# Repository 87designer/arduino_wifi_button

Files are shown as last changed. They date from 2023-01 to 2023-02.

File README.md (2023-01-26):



<!-- PROJECT LOGO -->
<br />
<div align="center">
  <a href="https://github.com/87designer/arduino_infant_tracker">
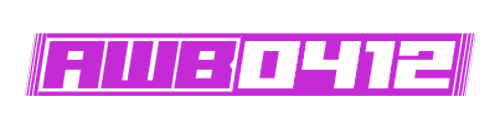
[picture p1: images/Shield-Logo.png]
    
  </a>

  <p align="center">
    <br />
    <!-- <a href="https://github.com/87designer/arduino_infant_tracker"><strong>Explore the docs »</strong></a>
    <br />
    <br />
    <a href="https://github.com/87designer/arduino_infant_tracker">View Demo</a> -->
  </p>
</div>

<!-- TABLE OF CONTENTS -->
<details>
  <summary>Table of Contents</summary>
  <ol>
    <li>
      <a href="#about-the-project">About The Project</a>
      <ul>
        <li><a href="#built-with">Built With</a></li>
      </ul>
    </li>
    <li>
      <a href="#getting-started">Getting Started</a>
      <ul>
        <li><a href="#prerequisites">Prerequisites</a></li>
        <li><a href="#installation">Installation</a></li>
      </ul>
    </li>
    <li><a href="#usage">Usage</a></li>
    <li><a href="#roadmap">Roadmap</a></li>
    <li><a href="#acknowledgments">Acknowledgments</a></li>
  </ol>
</details>

<!-- ABOUT THE PROJECT -->
## About The Project

After being introduced to Arduino and electronics through the "30 Days Lost in Space" Adventure Kit from Inventr, I was served a social media ad for a small consumer button device that logged events to a dashboard, via wifi. Seeing how I could potentially leverage a device like this in my day to day, my gears got to turning.

```
Arduino + New Electronic Skills = I can make that
```

And with that, the AWB0412 categorical data logging wifi button was born. *(as an Arduino Uno Shield)*

When the device is powered on the LED in the top left will be red. After successful network connectino has been made, the LED will turn Green. When a Button is pressed the LED will blink blue.

There are 4 buttons on the shield giving the ability to log up to 12 different types of events using the methods of single click, double click, & hold +1 second for each button.

<br>
<hr>

#### 3D Model with Components *(Designed using KiCad)*

<div style="display:flex">
     <div style="flex:1;padding-right:10px;">
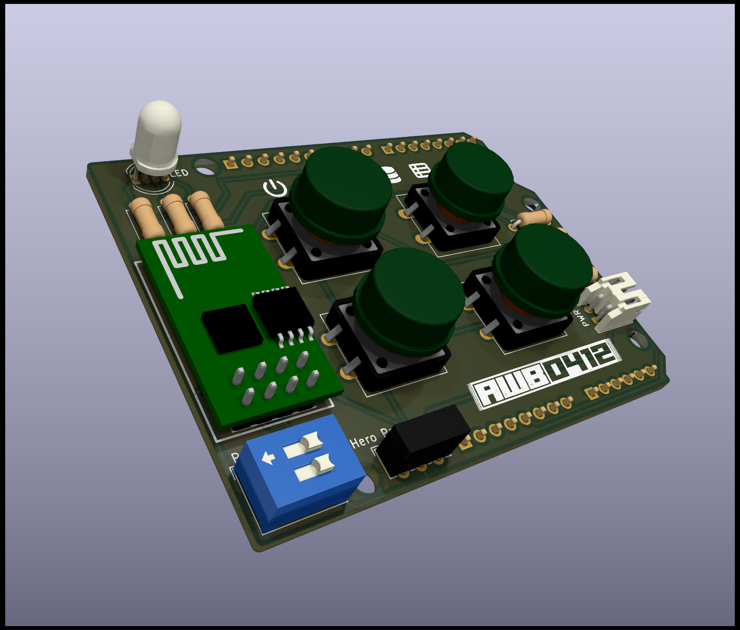
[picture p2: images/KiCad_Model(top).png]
          
     </div>
     <div style="flex:1;padding-left:10px;">
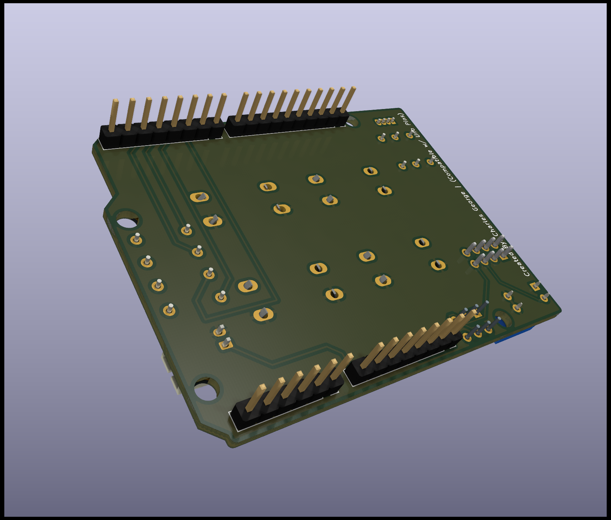
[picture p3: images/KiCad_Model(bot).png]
          
     </div>
</div>

<br>
<hr>

#### PCB *(Vendor Mockup from Gerber files)*

<div style="display:flex">
     <div style="flex:1;padding-right:10px;">
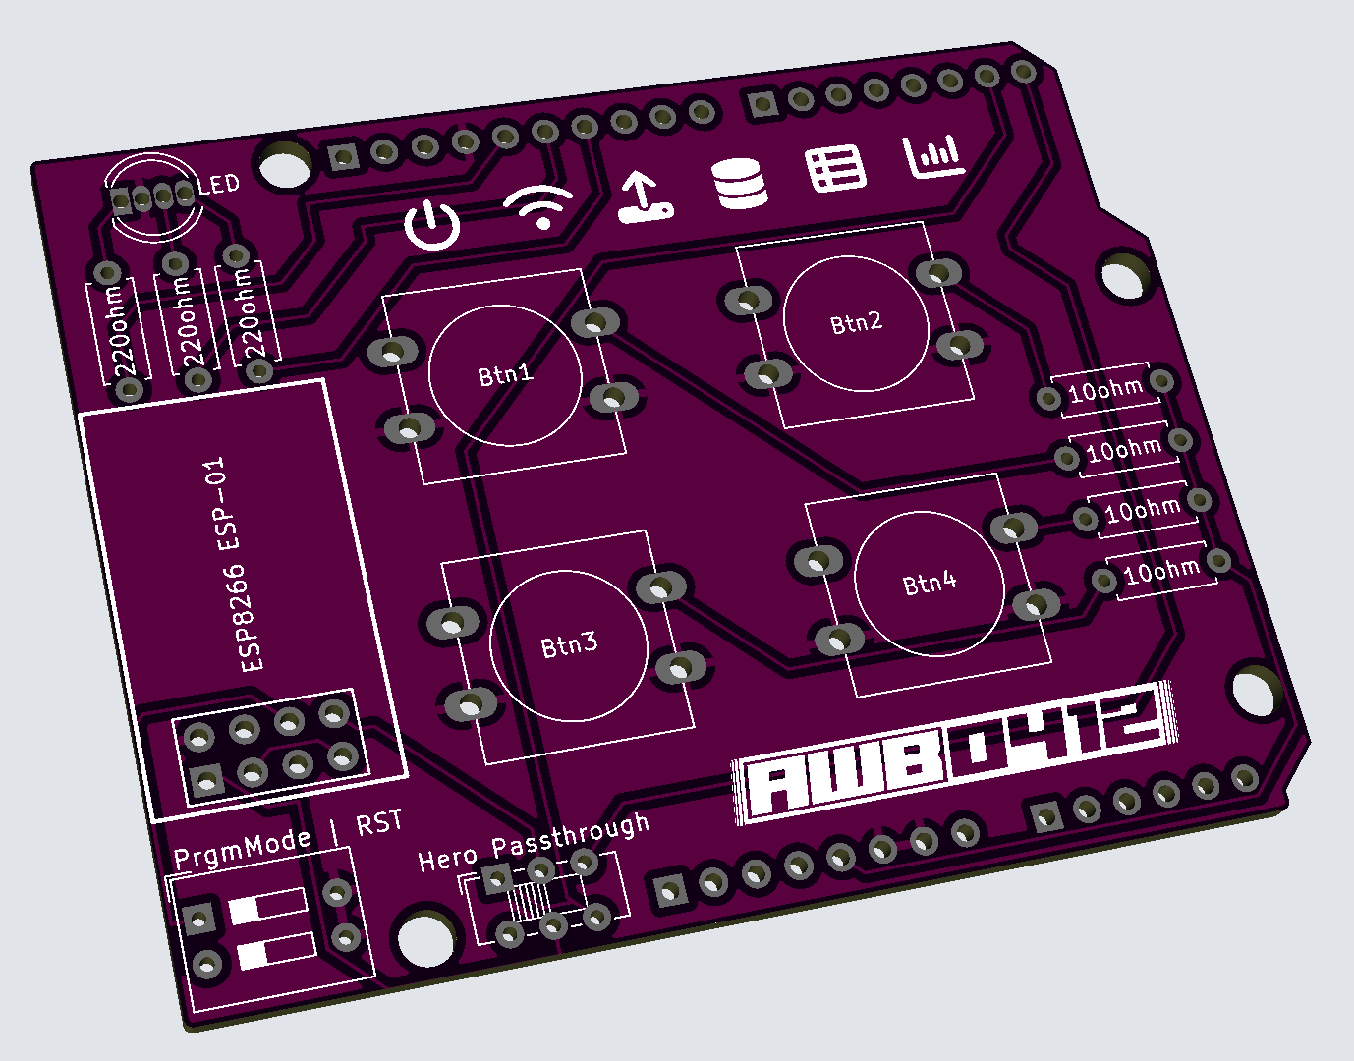
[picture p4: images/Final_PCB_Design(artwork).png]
          
     </div>
</div>

<p align="right">(<a href="#readme-top">back to top</a>)</p>

### Built With

* [][Arduino-url]
* [][Cplusplus-url]
* [][KiCad-url]
* [][googlesheets-url]
* [][appsscript-url]

<p align="right">(<a href="#readme-top">back to top</a>)</p>

<!-- GETTING STARTED -->
## Getting Started

### Prerequisites

1) Install the [Arudino IDE](https://www.arduino.cc/en/software) on your computer
2) Install appropriate [Drivers](https://inventr.io/drivers/) for the Hero board
3) Install [ESP Libraries](https://github.com/esp8266/Arduino)
4) [Configure Cloud](https://www.youtube.com/watch?v=fS0GeaOkNRw) storage and app
    - Setup a Google Sheet to accept the timestamps and categories.
    - Deploy Google Apps Script code to listen for category request and write it to the google sheet.

### Materials:
  * 1 x [Arduino Hero](https://github.com/inventrkits/HERO)
  * 1 x A-Male to B-Male USB Cable
  * 1 x [ESP8266](https://en.wikipedia.org/wiki/ESP8266) ESP-01 Wifi Module
  * 1 x AWB-0412 Arduino Uno Shield PCB
  * 1 x Pin Headers (1x10)
  * 2 x Pin Headers (1x08)
  * 1 x Pin Headers (1x06)
  * 4 x 10ohm Resistor
  * 3 x 220ohm Resistor
  * 1 x RGB LED
  * 4 x 12mm Tactile Button
  * 1 x [EG1271](https://www.digikey.com/en/products/detail/e-switch/EG1271/251335) DPDT Switch Slide
  * 1 x [78B02ST](https://www.digikey.com/en/products/detail/grayhill-inc/78B02ST/726238) DIP Switch Slide

### Installation

<!-- Write about install/uploading the code for hero & wifi module-->

After construction of the Shield is complete, mount the shield to the Arduino and connect to your computer using the compatible USB cable to power on.

1. Open up the Arduino IDE and ensure the correct Board and Port are selected.
2. With all switches on the shield in the operating position, upload a [blank sketch]() to the Arduino.
3. Power down / disconnect the USB cable and slide DPDT switch and top DIP switch *(this will enable programming mode for the wifi module when powered is restored)*.
5. Reconnect the USB and change the board assignment in the IDE to the ESP8266 wifi module *(the port should be the same so ensure it is still assigned)*
6. Upload the [wifi sketch]() to the ESP8266.
7. Once the sketch is finished uploading, slide the top DIP switch on and off to reset the wifi module.
8. Power down / disconnect the USB cable and return all switches to operating position.
9. Reconnect the USB and change the board assignment in the IDE back to the Arduino.
10. Upload the [button sketch]() to the Arduino.
11. Once the sketch is finished uploading, power down / disconnect the USB cable from the computer and the device is ready to operate from an appropriate power source (battery, wall plug, usb cable.)

<p align="right">(<a href="#readme-top">back to top</a>)</p>

<!-- USAGE EXAMPLES -->
## Usage

#### Infant Tracker

One usage example of the AWB0412 wifi button shield would be as an Infant Tracker to help sleep deprived parents keep track of diapers, feedings, sleep schedule etc.

<p align="right">(<a href="#readme-top">back to top</a>)</p>

<!-- ROADMAP -->
## Roadmap

- [x] Breadboard Prototype to test functionality<br>
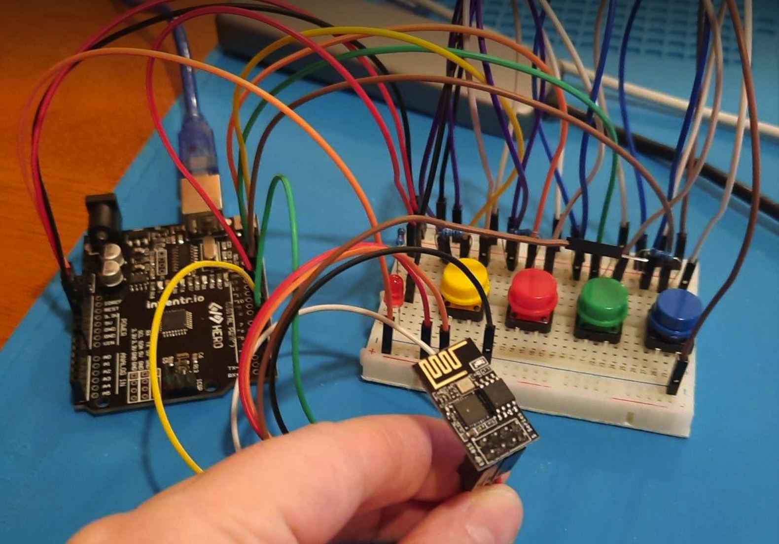
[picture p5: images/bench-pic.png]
  
- [x] Document Prototype in hobby CAD software (Tinkercad / Fritzing)<br>
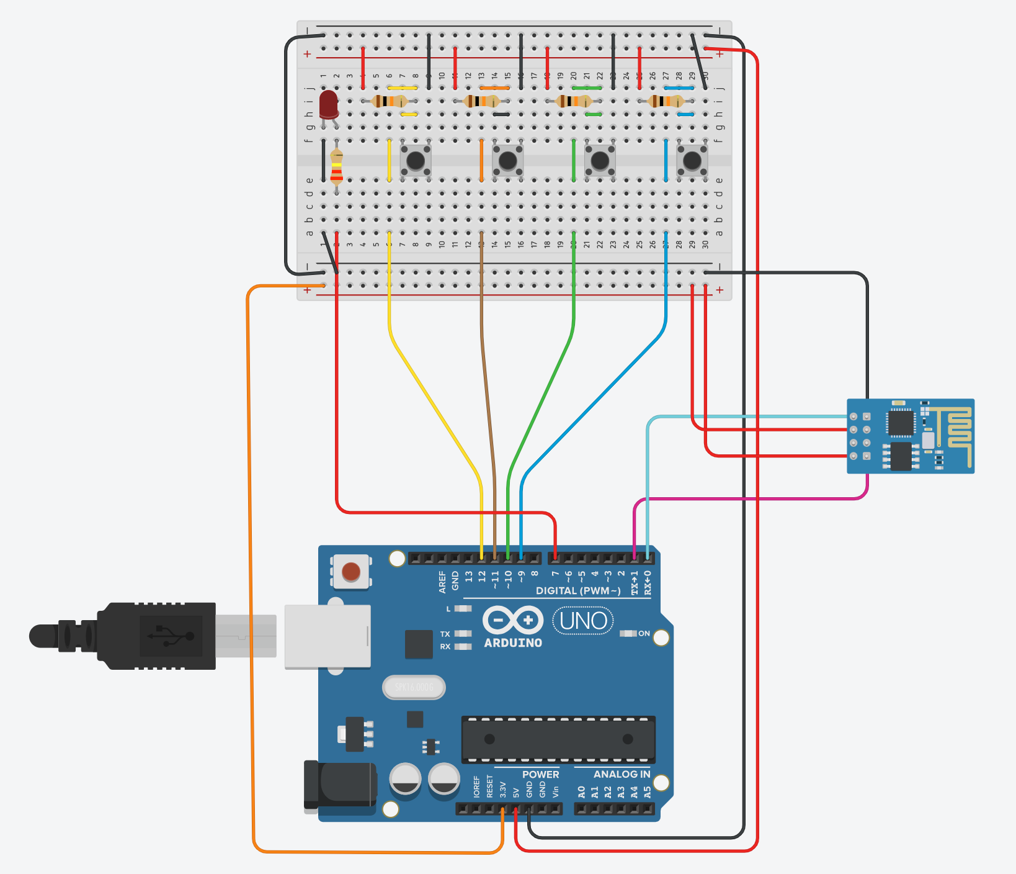
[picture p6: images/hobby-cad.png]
  
- [x] Electronic Design Automation (EDA), and 
    - [x] Schematic Capture<br>
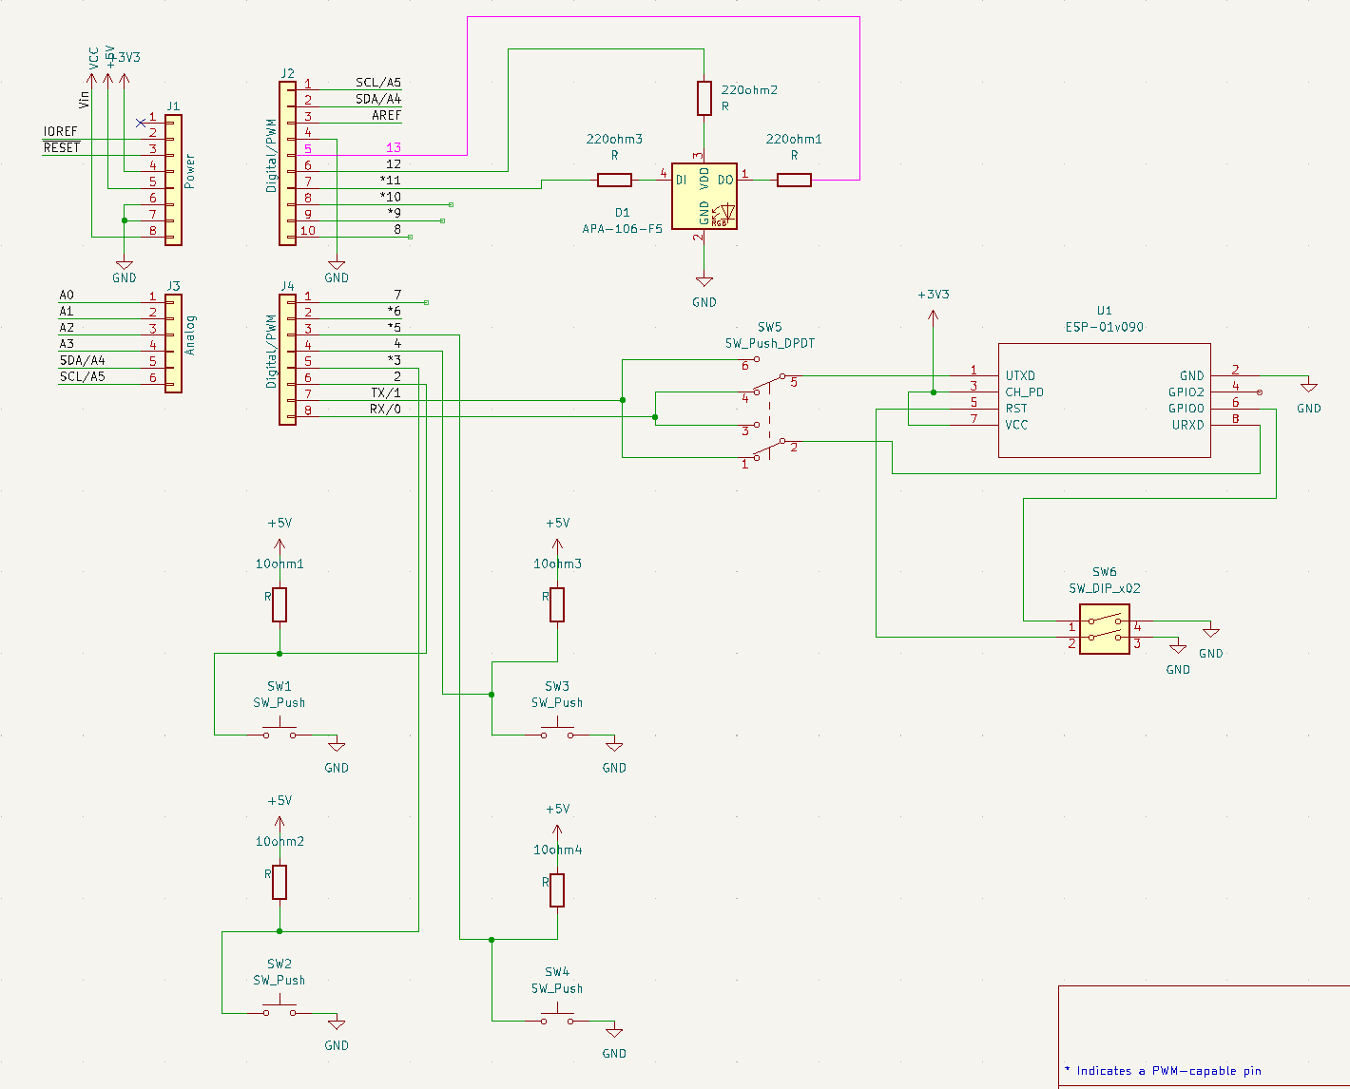
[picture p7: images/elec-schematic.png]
      
    - [x] PCB Layout with Gerber output<br>
      <div style="display:flex">
        <div style="flex:1;padding-right:10px;">
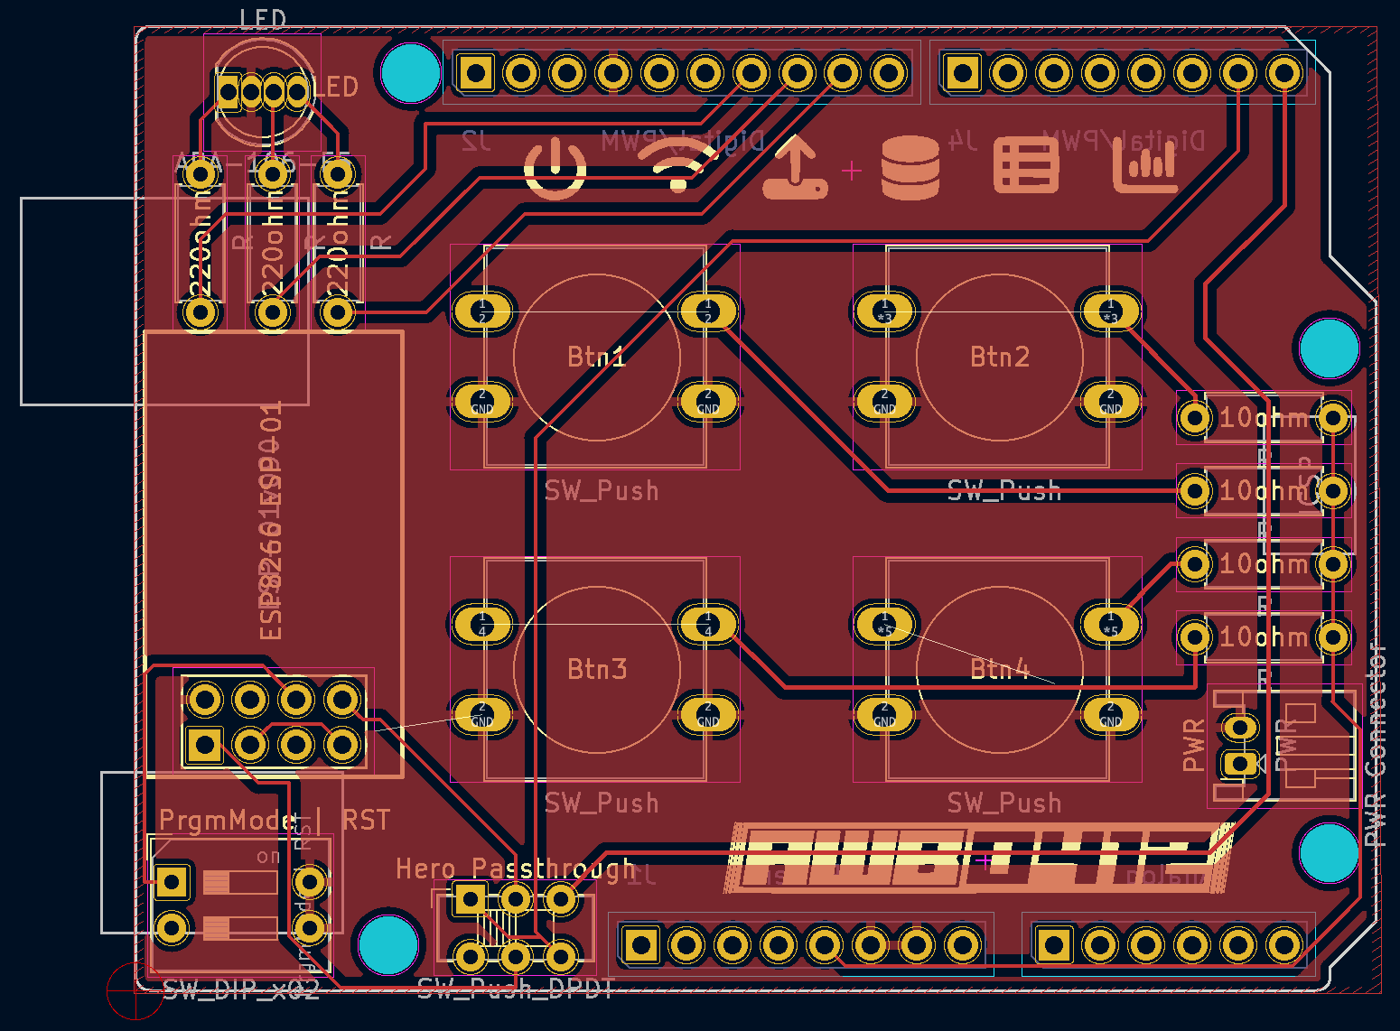
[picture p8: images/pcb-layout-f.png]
          
        </div>
        <div style="flex:1;padding-right:10px;">
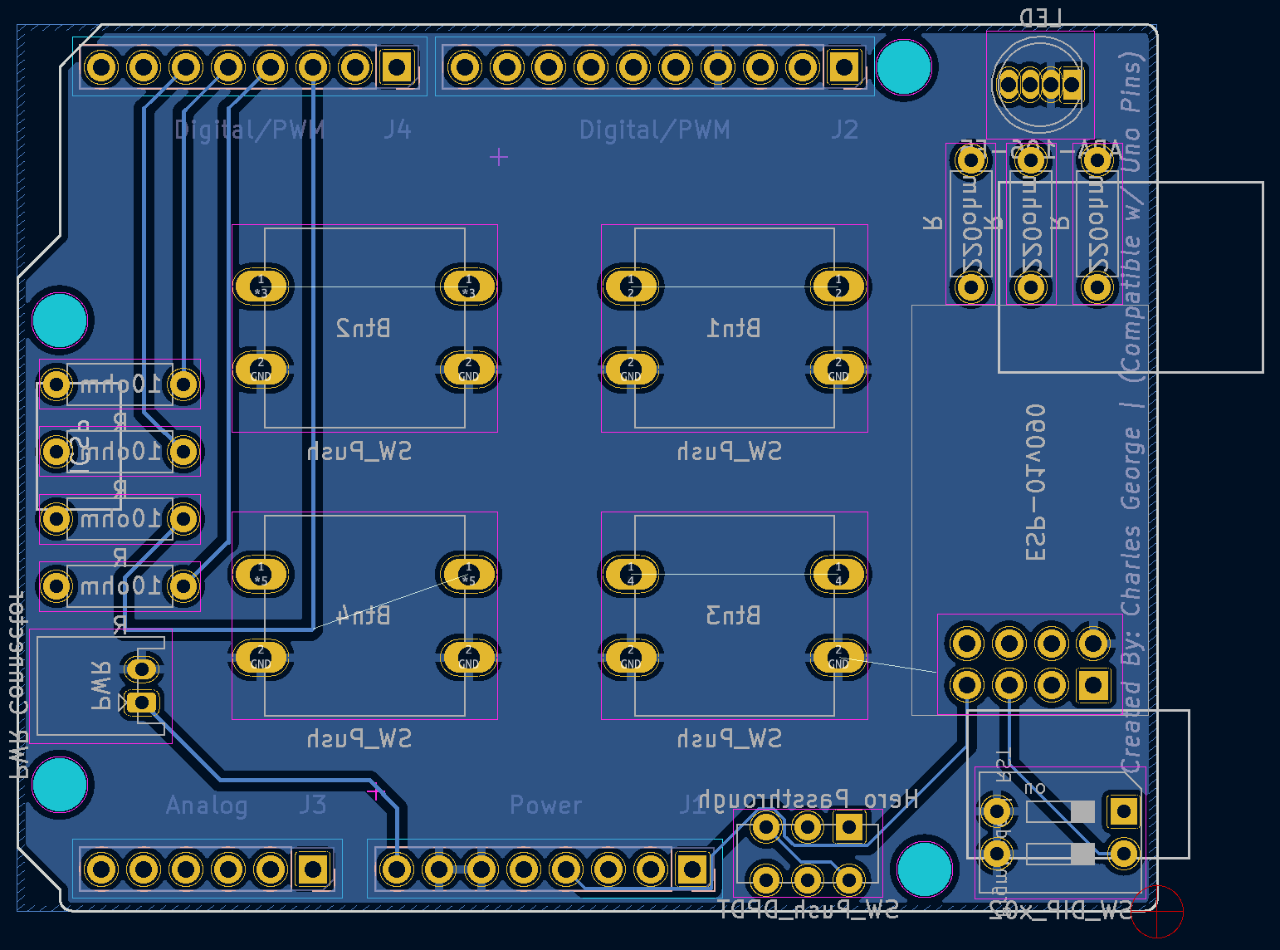
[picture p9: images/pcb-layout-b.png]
          
        </div>
      </div>
- [ ] Develop Final button commands
- [ ] Develop Method of Powering Device
- [ ] Draft Documentation
- [ ] Assemble Shield & Test Hardware
- [ ] Finalize Documentation
- [ ] Design / Fabricate a Housing possibly 3D printed model

<p align="right">(<a href="#readme-top">back to top</a>)</p>

<!-- ACKNOWLEDGMENTS -->
## Acknowledgments

* Special shoutout to the [Inventr](https://inventr.io/) Adventure Kit for laying the foundation for electronics that helped bring this project to life.
* [LogMaker360](https://www.youtube.com/watch?v=fS0GeaOkNRw) Youtube video walkthrough on how to get arduino to write to google sheets.
* [Electronics Hub](https://www.electronicshub.org/esp8266-arduino-interface/) Great article with detailed information regarding the ESP8266 ESP-01
* [Gerber/Drill File Generation Guide](https://support.jlcpcb.com/article/194-how-to-generate-gerber-and-drill-files-in-kicad-6) for PCB production at JLCPCB when using KiCad 6
* [Best-README-Template](https://github.com/othneildrew/Best-README-Template)

<p align="right">(<a href="#readme-top">back to top</a>)</p>

<!-- MARKDOWN LINKS & IMAGES -->
<!-- https://www.markdownguide.org/basic-syntax/#reference-style-links -->
[Arduino]: https://img.shields.io/badge/arduino-00979D?style=for-the-badge&logo=arduino&logoColor=white
[Arduino-url]: https://www.arduino.cc/
[Cplusplus]: https://img.shields.io/badge/C++-00599C?style=for-the-badge&logo=cplusplus&logoColor=white
[Cplusplus-url]: https://en.wikipedia.org/wiki/C%2B%2B
[KiCad]: https://img.shields.io/badge/KiCad-314CB0?style=for-the-badge&logo=kicad&logoColor=white
[KiCad-url]: https://www.kicad.org/
[googlesheets]: https://img.shields.io/badge/Google%20Sheets-34A853?style=for-the-badge&logo=googlesheets&logoColor=white
[googlesheets-url]: https://www.google.com/sheets/about/
[appsscript]: https://img.shields.io/badge/Google%20Apps%20Script-4285F4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
[appsscript-url]: https://www.google.com/script/start/

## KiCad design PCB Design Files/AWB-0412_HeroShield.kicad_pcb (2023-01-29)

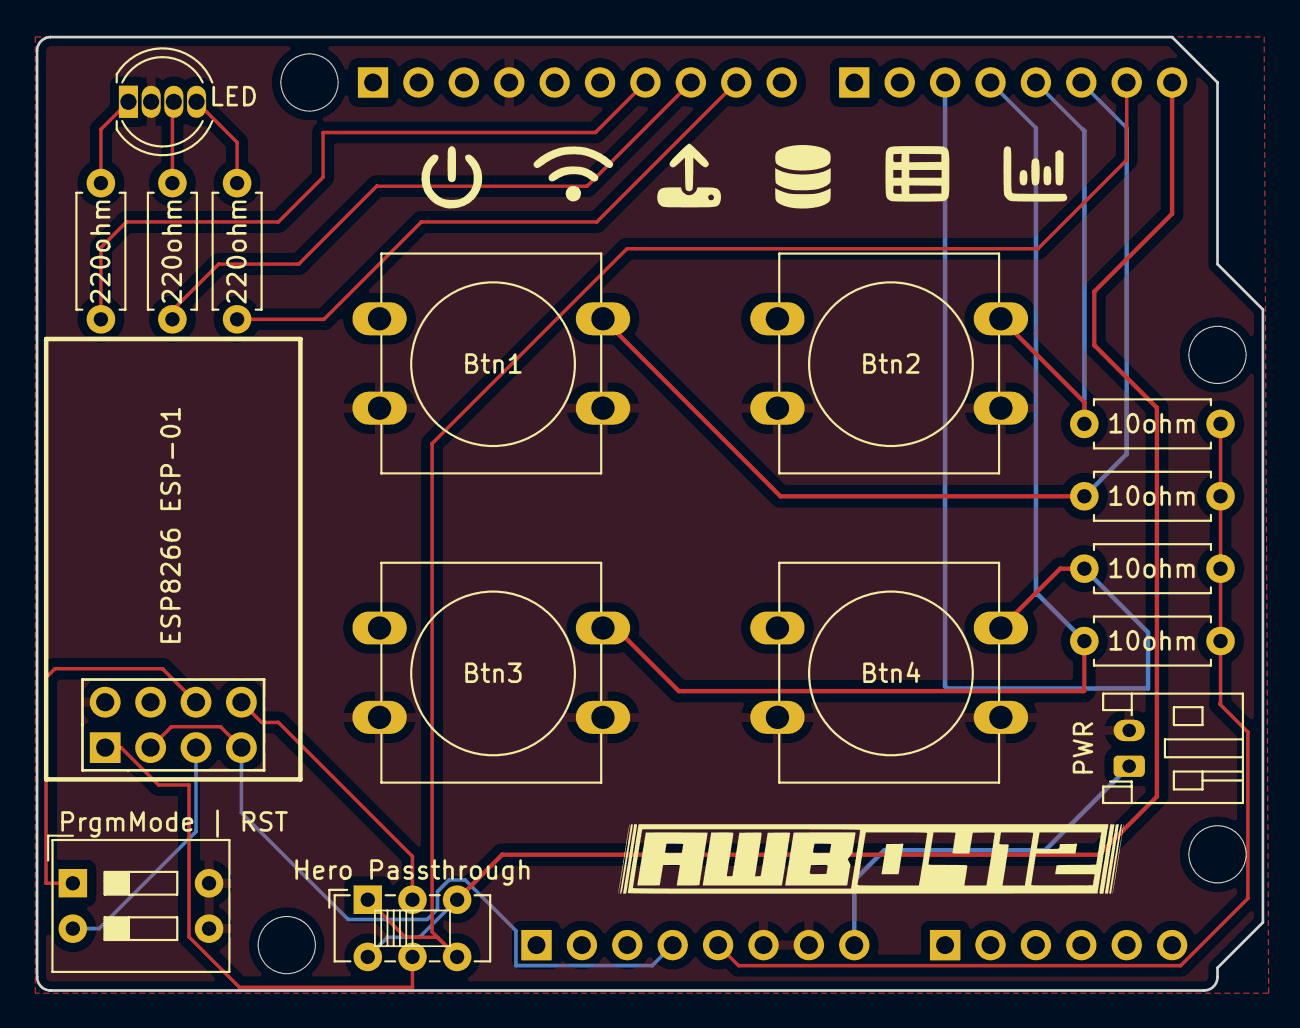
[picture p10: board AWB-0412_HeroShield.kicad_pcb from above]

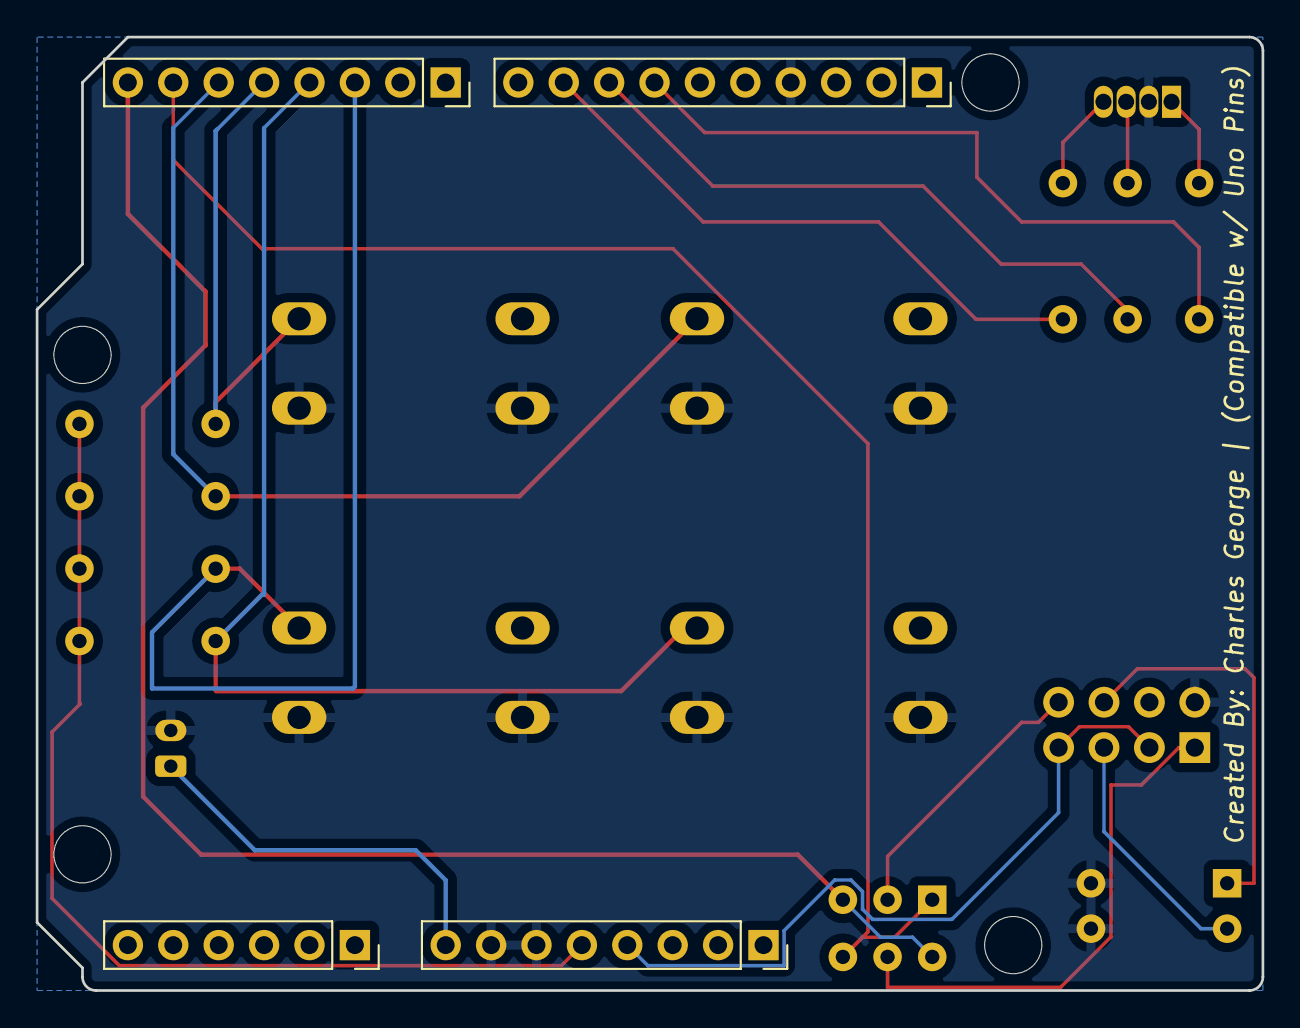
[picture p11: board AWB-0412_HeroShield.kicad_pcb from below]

Board: 2 copper layers, 68.6 x 53.3 mm, 24 parts (4 on the bottom side), 22 nets.

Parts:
10ohm, 10ohm#2, 10ohm#3, 10ohm#4, 220ohm, 220ohm#2, 220ohm#3: R; R_Axial_DIN0207_L6.3mm_D2.5mm_P7.62mm_Horizontal
Btn1, Btn2, Btn3, Btn4: SW_Push; SW_PUSH-12mm
ESP8266 ESP-01: ESP-01v090; ESP-01
Hero Passthrough: SW_Push_DPDT; SW_E-Switch_EG1271_SPDT
J1: Power; PinSocket_1x08_P2.54mm_Vertical
J2: Digital/PWM; PinSocket_1x10_P2.54mm_Vertical
J3: Analog; PinSocket_1x06_P2.54mm_Vertical
J4: Digital/PWM; PinSocket_1x08_P2.54mm_Vertical
LED: APA-106-F5; LED_D5.0mm-4_RGB
MH1, MH2, MH3, MH4: MountingHole_3.2mm
PWR: JST_PH_S2B-PH-K_1x02_P2.00mm_Horizontal
PrgmMode | RST: SW_DIP_x02; SW_DIP_SPSTx02_Slide_9.78x7.26mm_W7.62mm_P2.54mm

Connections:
+3V3: ESP8266 ESP-01.3 (CH_PD), ESP8266 ESP-01.7 (VCC), J1.4
+5V: 10ohm.2, 10ohm#2.2, 10ohm#3.2, 10ohm#4.2, J1.5
/2: 10ohm#3.1, Btn1.1, J4.6
/4: 10ohm.1, Btn3.1, J4.4
/*3: 10ohm#2.1, Btn2.1, J4.5
/*5: 10ohm#4.1, Btn4.1, J4.3
/*9: 220ohm#3.1, J2.9
/*10: 220ohm.1, J2.8
/*11: 220ohm#2.1, J2.7
/RX/0: Hero Passthrough.3 (C), Hero Passthrough.4 (A), J4.8
/SCL/A5: J2.1, J3.6
/SDA/A4: J2.2, J3.5
/TX/1: Hero Passthrough.1 (A), Hero Passthrough.6 (C), J4.7
GND: Btn1.2, Btn2.2, Btn3.2, Btn4.2, ESP8266 ESP-01.2 (GND), J1.6, J1.7, J2.4, LED.2 (GND), PWR.2, PrgmMode | RST.3, PrgmMode | RST.4
unnamed: 220ohm.2, LED.3 (VDD)
unnamed: 220ohm#3.2, LED.4 (DI)
unnamed: 220ohm#2.2, LED.1 (DO)
unnamed: ESP8266 ESP-01.8 (URXD), Hero Passthrough.2 (B)
unnamed: ESP8266 ESP-01.1 (UTXD), Hero Passthrough.5 (B)
unnamed: ESP8266 ESP-01.6 (GPIO0), PrgmMode | RST.1
unnamed: ESP8266 ESP-01.5 (RST), PrgmMode | RST.2
VCC: J1.8, PWR.1

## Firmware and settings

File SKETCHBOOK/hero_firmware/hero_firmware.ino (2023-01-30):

// ---------------------------
// Multi-Button Controller
// ---------------------------

#include <OneButton.h>  // Button Library

// ---------------------------
// VARIABLES
// ---------------------------
const int btn1Pin = 2;
const int btn2Pin = 3;
const int btn3Pin = 4;
const int btn4Pin = 5;

int red = 9;
int green = 10;
int blue = 11;

OneButton btn1(btn1Pin, true);
OneButton btn2(btn2Pin, true);
OneButton btn3(btn3Pin, true);
OneButton btn4(btn4Pin, true);

String wet = "Wet-Diaper";
String dirty = "Dirty-Diaper";
String mixed = "Mixed-Diaper";
String feeding = "Feeding";
String sleepWake = "Sleep-Wake";

int redLED[]={125,0,0};
int greenLED[]={0,125,0};
int blueLED[]={0,0,125};
int* colorStatus=redLED;
// ---------------------------

void RGB_color(int red_value, int green_value, int blue_value) {
  // custom function to set three PWM color channels to any given mixture
  analogWrite(red, red_value);
  analogWrite(green, green_value);
  analogWrite(blue, blue_value);
}

void setup() {
  Serial.begin(115200);

  pinMode(red, OUTPUT);
  RGB_color(colorStatus[0],colorStatus[1],colorStatus[2]);
  pinMode(green, OUTPUT);
  pinMode(blue, OUTPUT);

  pinMode(btn1Pin, INPUT);
  pinMode(btn2Pin, INPUT);
  pinMode(btn3Pin, INPUT);
  pinMode(btn4Pin, INPUT);

  btn1.attachDoubleClick(doubleClick1);
  btn2.attachDoubleClick(doubleClick2);
  btn2.attachLongPressStart(longClick2);
  btn3.attachDoubleClick(doubleClick3);
  btn4.attachDoubleClick(doubleClick4);
}

void loop () {
  if (Serial.available()) {
    String wifiStatus = Serial.readStringUntil('\r\n');
    wifiStatus.trim();
    if (wifiStatus == "Y") {
      colorStatus = greenLED;
      RGB_color(colorStatus[0],colorStatus[1],colorStatus[2]);
    } if (wifiStatus == ".") {
      colorStatus = redLED;
      RGB_color(colorStatus[0],colorStatus[1],colorStatus[2]);
    }
  }

  // Establish Button logic here
  btn1.tick();
  btn2.tick();
  btn3.tick();
  btn4.tick();

  delay(10);
}

// ---------------------------
// LED BLINK MODES
// ---------------------------
void singleBlinkLED(){
    RGB_color(0, 0, 125); // Blue
    delay(100);
    RGB_color(0, 0, 0);
    delay(100);
    RGB_color(colorStatus[0],colorStatus[1],colorStatus[2]);
    }

void doubleRedBlinkLED(){
    RGB_color(125, 0, 0); // Blue
    delay(100);
    RGB_color(0, 0, 0);
    delay(100);
    RGB_color(125, 0, 0); // Blue
    delay(100);
    RGB_color(0, 0, 0);
    delay(100);
    RGB_color(colorStatus[0],colorStatus[1],colorStatus[2]);
    }

void doubleBlueBlinkLED(){
    RGB_color(0, 0, 125); // Blue
    delay(100);
    RGB_color(0, 0, 0);
    delay(100);
    RGB_color(0, 0, 125); // Blue
    delay(100);
    RGB_color(0, 0, 0);
    delay(100);
    RGB_color(colorStatus[0],colorStatus[1],colorStatus[2]);
    }

void longBlinkLED(){
    RGB_color(0, 0, 125); // Blue
    delay(1000);
    RGB_color(colorStatus[0],colorStatus[1],colorStatus[2]);
    }

// ---------------------------
// BUTTONS
// ---------------------------
void doubleClick1() {
  Serial.println(wet);
  doubleBlueBlinkLED();
}

void doubleClick2() {
  Serial.println(dirty);
  doubleBlueBlinkLED();
}

void longClick2(){
  Serial.println(mixed);
  longBlinkLED();
}

void doubleClick3() {
  Serial.println(feeding);
  doubleBlueBlinkLED();
}

void doubleClick4() {
  Serial.println(sleepWake);
  doubleBlueBlinkLED();
}

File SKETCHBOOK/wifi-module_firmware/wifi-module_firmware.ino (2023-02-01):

//Connect to Network | Send Button Data to Google Sheets.
#include <ESP8266WiFi.h>
#include <ESP8266Ping.h>
#include <WiFiClientSecure.h>
#include <WiFiManager.h> // https://github.com/tzapu/WiFiManager

const char * host = "script.google.com";
const int httpsPort = 443;
// Use WiFiClientSecure class to create TLS connection
WiFiClientSecure client;
// SHA1 fingerprint of the certificate
const char* fingerprint = "67 12 5D A1 8A F5 FD EC 11 FD 73 61 69 A8 4C 3F 3A B9 C2 18";
String GAS_ID = "<Place Google App Script ID here>";
String wifiStatus;

void setup() {
  // WiFi.mode(WIFI_STA); // explicitly set mode, esp defaults to STA+AP
  // it is a good practice to make sure your code sets wifi mode how you want it.

  // put your setup code here, to run once:
  client.setInsecure();
  Serial.begin(115200);
  while (!Serial);

  //WiFiManager, Local intialization. Once its business is done, there is no need to keep it around
  WiFiManager wm;

  // reset settings - wipe stored credentials for testing
  // these are stored by the esp library
  wm.resetSettings();
  wm.setClass("invert"); // dark theme

  // Automatically connect using saved credentials,
  // if connection fails, it starts an access point with the specified name ( "AutoConnectAP"),
  // if empty will auto generate SSID, if password is blank it will be anonymous AP (wm.autoConnect())
  // then goes into a blocking loop awaiting configuration and will return success result

  bool res;
  // res = wm.autoConnect(); // auto generated AP name from chipid
  res = wm.autoConnect("<Place Name of IOT device here>"); // anonymous ap
  // res = wm.autoConnect("<Place Name of IOT device here>","password"); // password protected ap

  if(!res) {
    Serial.println("Failed to connect");
    // ESP.restart();
  }
  else {
    //if you get here you have connected to the WiFi
    Serial.println("Connected");
    wifiStatus = "Y";
    Serial.println(wifiStatus);
  }
}

void loop() {
  if(Ping.ping(host)) {
    wifiStatus = "Y";
    Serial.println(wifiStatus);
  } else {
    wifiStatus = ".";
    Serial.println(wifiStatus);
  }

  // put your main code here, to run repeatedly:
  if (Serial.available()) {
    String SerialResponse = Serial.readStringUntil('\r\n');
    Serial.println(SerialResponse);
    sendData(SerialResponse);
  }

  delay(10);
}


// Function to send data into GoogleSheet
void sendData(String btn){
  Serial.print("connecting to ");
  Serial.println(host);

  if (!client.connect(host, httpsPort)) {
    Serial.println("connection failed");
    return;
  }

  if (client.verify(fingerprint, host)) {
    Serial.println("certificate matches");
  } else {
    Serial.println("certificate doesn't match");
  }

  String string_button = btn;
  String url = "/macros/s/" + GAS_ID + "/exec?button=" + string_button;

  Serial.print("requesting URL: ");
  Serial.println(url);
  client.print(String("GET ") + url + " HTTP/1.1\r\n" +
         "Host: " + host + "\r\n" +
         "User-Agent: BuildFailureDetectorESP8266\r\n" +
         "Connection: close\r\n\r\n");
  Serial.println("request sent");
}

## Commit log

2023-01-24 Added PCB images
2023-01-26 Add PCB files
    [AWB-0412_HeroShield-B_Cu.gbl, AWB-0412_HeroShield-B_Mask.gbs, AWB-0412_HeroShield-B_Paste.gbp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]
2023-01-26 Add Arduino Sketch and Google App Script code
2023-01-26 Update to Component List
    [AWB-0412_HeroShield.csv]
2023-01-29 Update PCB files
    Updated the PCB files. Altered LED connections to ensure analog out compatible pins were connected to the LED. As well as added a JST PH 2-Pin connector for providing power.
    [AWB-0412_HeroShield-B_Cu.gbl, AWB-0412_HeroShield-B_Mask.gbs, AWB-0412_HeroShield-B_Paste.gbp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]
